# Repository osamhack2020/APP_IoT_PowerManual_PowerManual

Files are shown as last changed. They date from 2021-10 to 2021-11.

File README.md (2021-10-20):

# Project Name: PowerManual
  

## 프로잭트 소개
 - 군대에 들어오고 나서 흔히들 시작하는것 중 하나는 바로 헬스입니다. 20대의 젊은 나이에 멋진 몸을 만들고자 많은 장병들이 부대내 체단실을 이용하면서 하루하루 노력하고 있지만 전문가의 도움 없이 하기에는 어려움도 있고 부상의 위험도 있는 실상입니다. 처음 해보는 장병들은 어떻게 자세를 잡아야할지도 모르겠고 사회에서 헬스를 하다가 온 장병들도 혼자 하다보니 잘못된 자세로 인한 허리부상, 관절부상등을 입는 사례를 종종 목격하고는 합니다. 이렇게 헬스를 할때 가장 중요한 올바른 자세를 정확하게 잡고자 PowerManual은 운동자세 측정 디바이스와 앱을 제공합니다.

## 기능 설명
### 운동자세 측정 디바이스
 - 주기능:  
        디바이스가 착용된 부위의 움직임을 추적하여 운동을 올바른 자세로 하고 있는지 실시간으로 판단하여 판단 결과를 앱으로 전송해줍니다.

 - 구성:  
         
       <팔 또는 다리에 착용할 수 있는 스트랩 형태 *[Tinkercad로 렌더링 예정]*>  
   - 스트랩은 운동할 때 원래 부상방지, 힘 보조등의 이유로 많이 사용되는 만큼 운동할 때 사용자에게 크게 방해가 되지 않는 디자인으로 선정하였습니다.

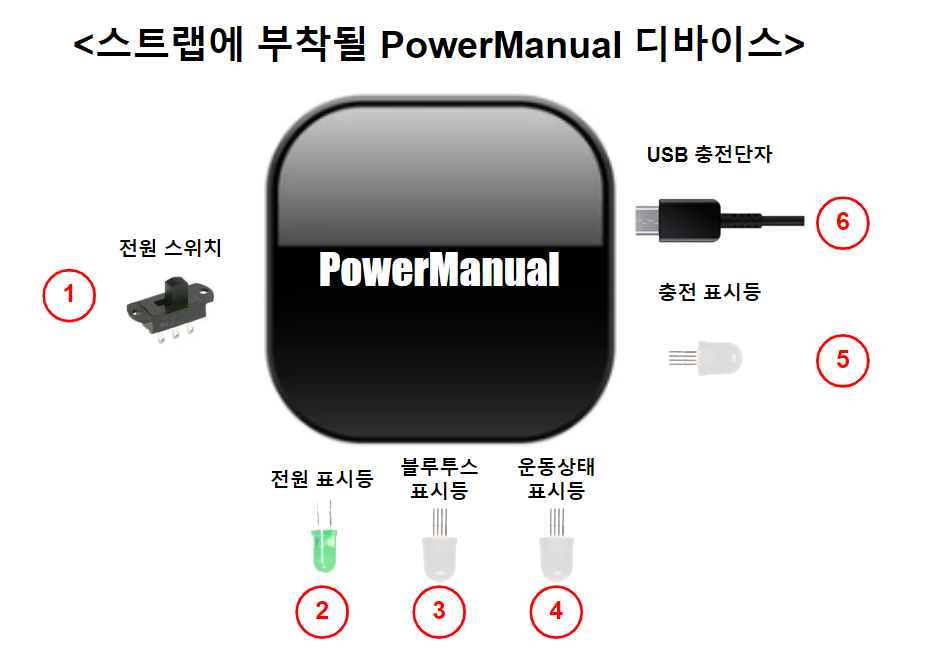
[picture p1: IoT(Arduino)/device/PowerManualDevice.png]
   

   1. 슬라이드 스위치: 디바이스의 전원을 on/off 합니다.   
   2. 내부 MCU LED: 디바이스의 전원이 on이면 초록불이, off면 꺼집니다.  
   3. 내부 블루투스 모듈 LED: 블루투스 기기와 연결되어 있지 않으면 빨간불, 연결 중이면 노란불, 연결상태면 초록불이 켜집니다.   
   4. RGB LED: 앱에서 운동시작 버튼을 누르면 준비자세를 취할 때까지 노란불이 켜지며 준비자세를 유지하면 초록불로 바뀌면서 2초후 운동시작을 나타냅니다. 운동중 자세가 잘못되면 빨간불로 알려줍니다.  
   5. 내부 충전 모듈 LED: 충전중일때는 빨간불이 켜지며 충전이 완료되면 파란불이 켜집니다.  
   6. 내부 충전 모듈 USB 단자: USB충전을 위한 단자가 달려있습니다.  

 - 디바이스 내부:  
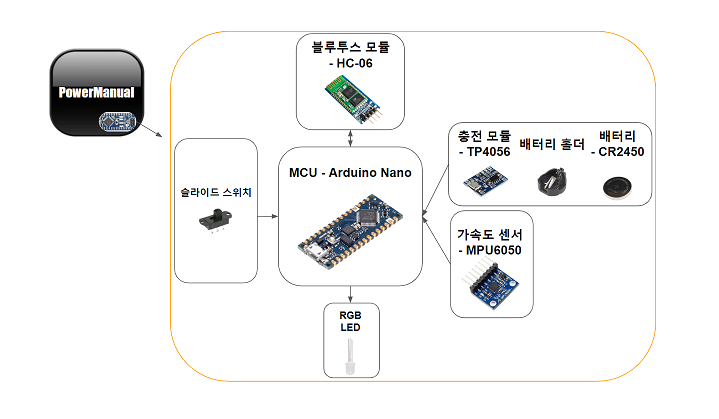
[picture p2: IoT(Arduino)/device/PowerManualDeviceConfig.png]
    

 - 내부 회로도:  
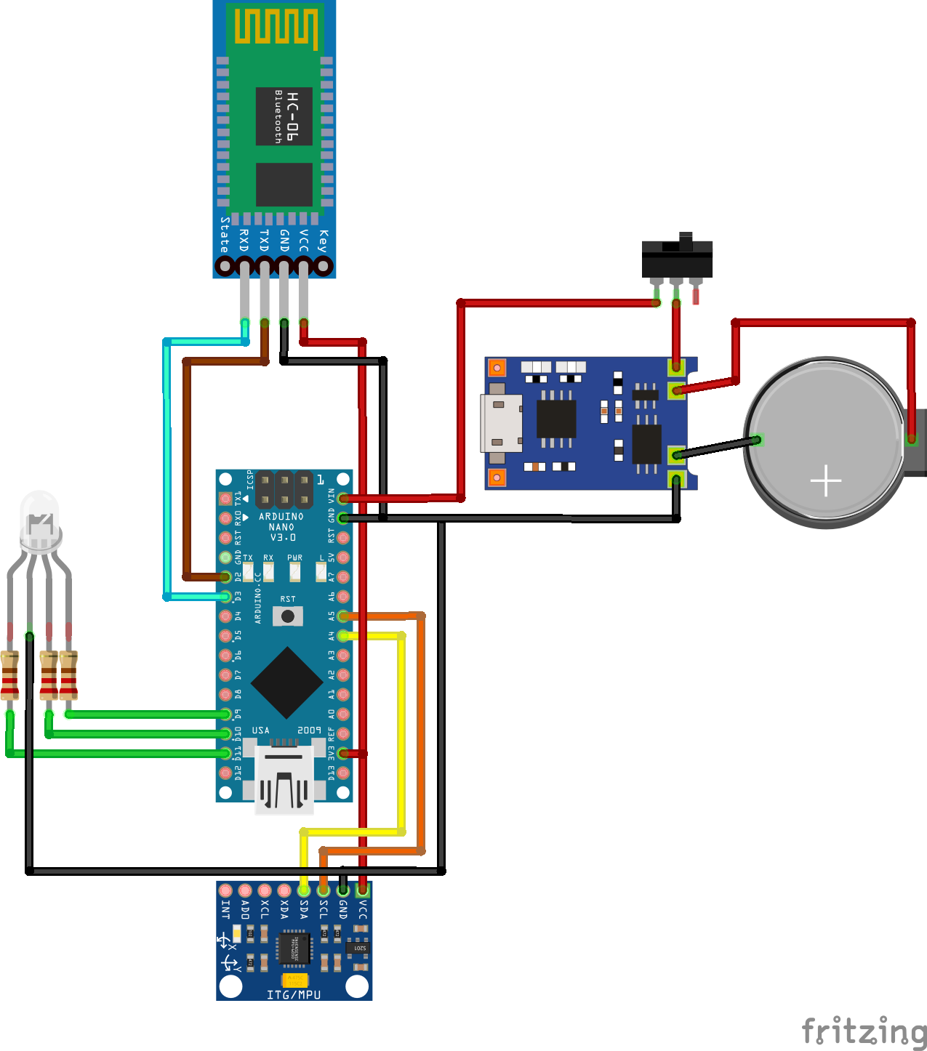
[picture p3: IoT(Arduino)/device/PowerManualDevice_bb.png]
     

## 테스트 모듈 착용 이미지
- 스쿼트 시연시 아래와 같이 허벅지에 착용함
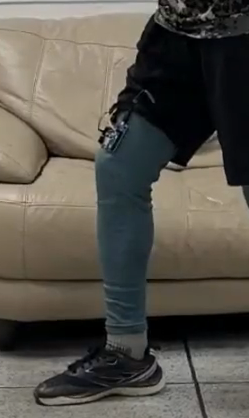
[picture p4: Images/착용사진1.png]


## 시연 영상
* [전원스위치와 LED 시뮬레이션](https://youtu.be/p0WgclJNXeo)
* [스쿼트측정과 운동상태 LED 시뮬레이션](https://youtu.be/8TwuZ1K5hpM)
* [스쿼트측정 시연영상](https://youtu.be/hADi2CqFvGY)
* [종합 시연영상](https://youtu.be/UrrtCfTJw_U)   

## APP

### 화면  
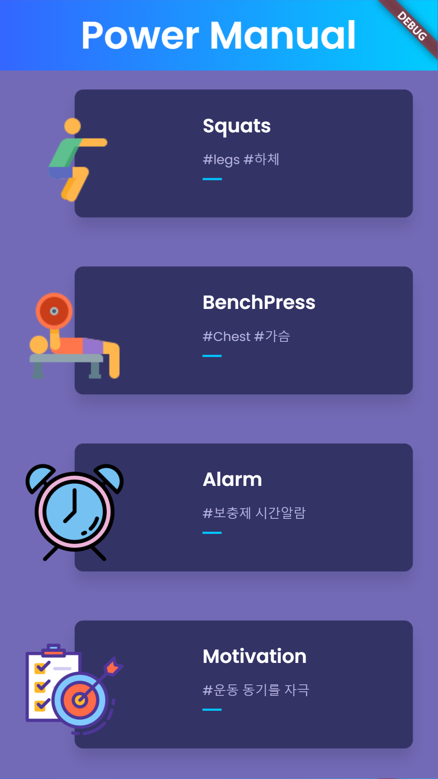
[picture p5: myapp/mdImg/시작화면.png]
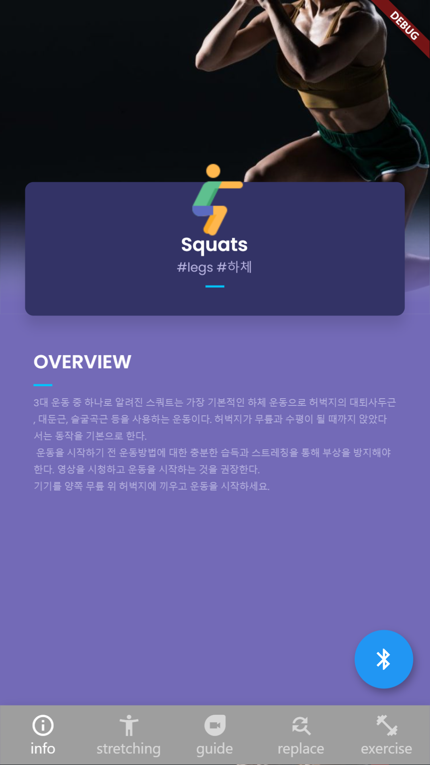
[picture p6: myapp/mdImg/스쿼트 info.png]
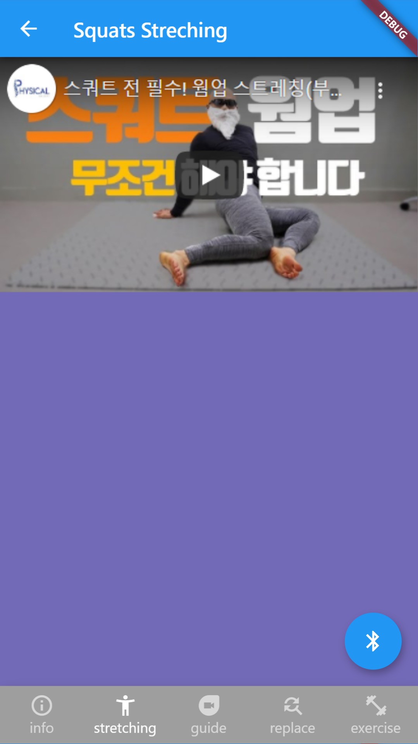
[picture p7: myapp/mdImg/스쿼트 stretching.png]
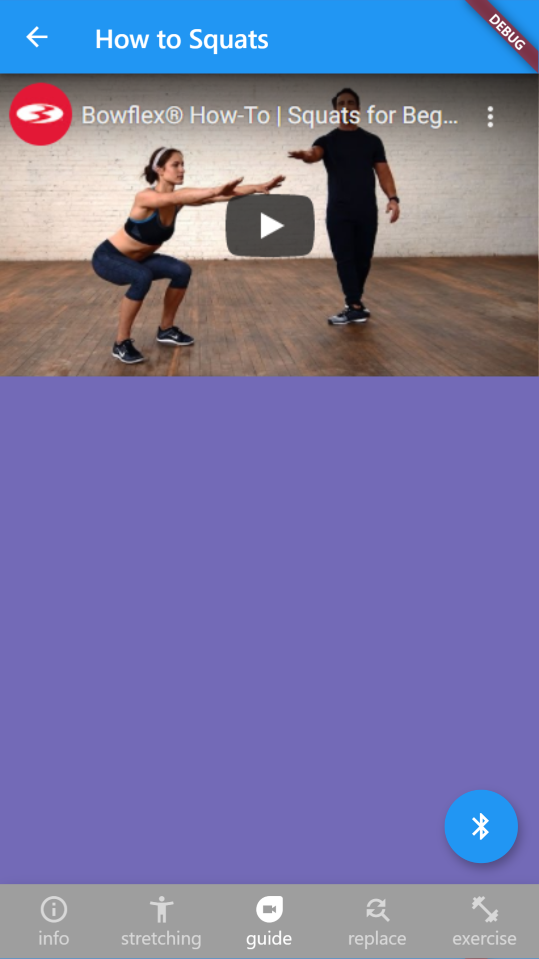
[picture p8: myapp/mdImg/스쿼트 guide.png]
   |  </br> 시작화면|  </br> 스쿼트 info |  </br> 스쿼트 스트레칭 |   </br> 스쿼트 가이드 |
| :------------: | :------------: | :------------: | :------------: |
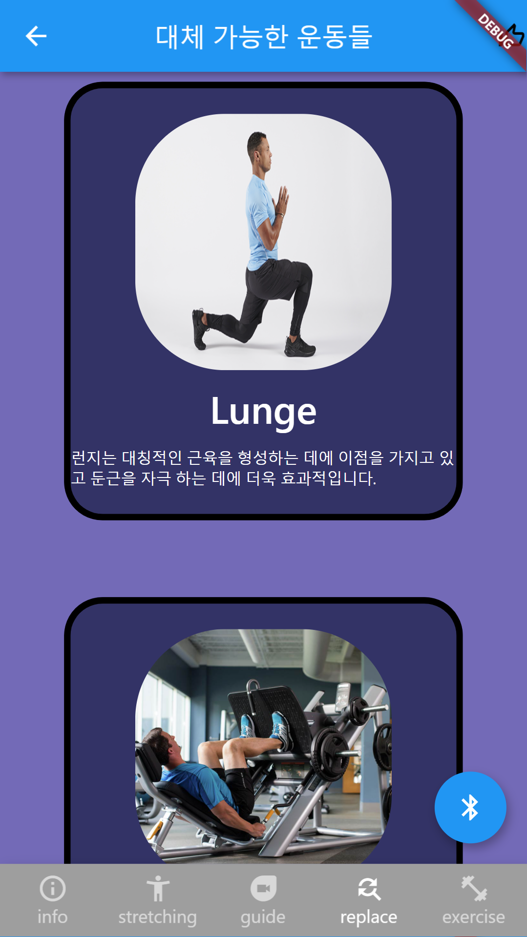
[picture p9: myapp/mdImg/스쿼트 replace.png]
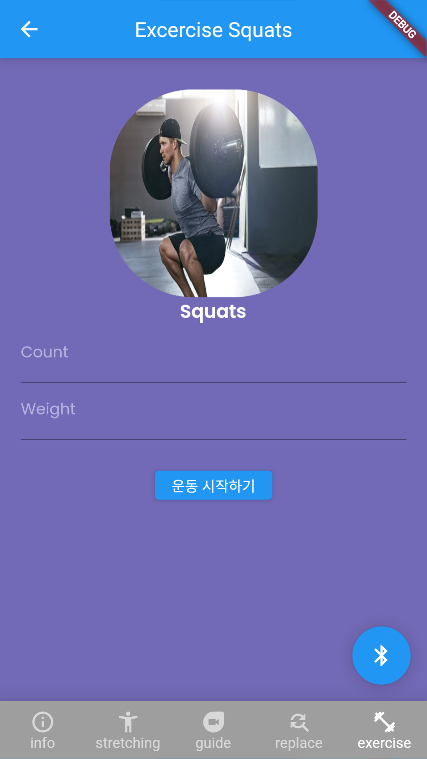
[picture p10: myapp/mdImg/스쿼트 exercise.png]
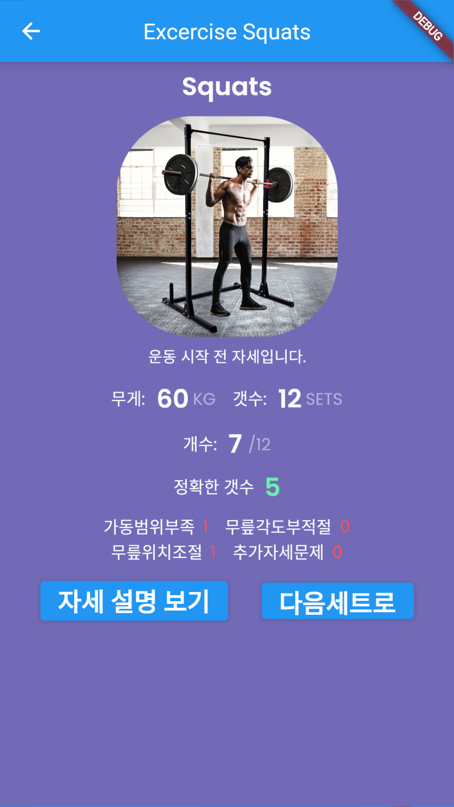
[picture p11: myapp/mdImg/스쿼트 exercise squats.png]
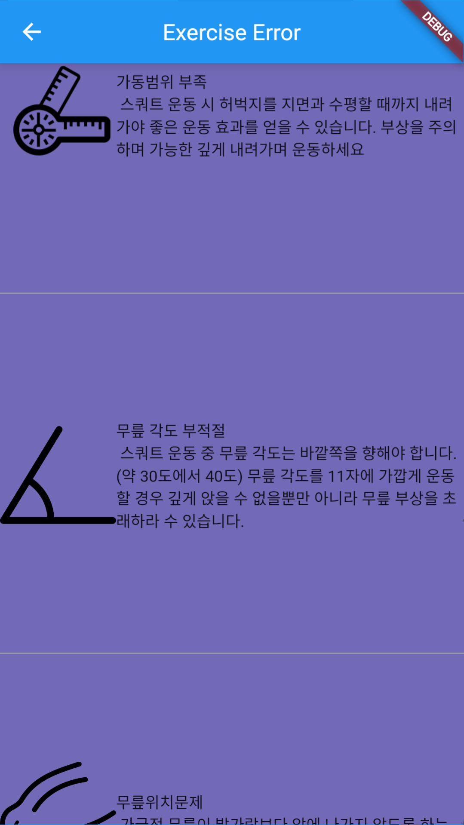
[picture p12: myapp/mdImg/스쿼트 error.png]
|  </br> 스쿼트 대체운동  |  </br> 스쿼트 운동 시작  |   </br> 스쿼트 운동화면 |   </br> 잘못된 자세 교정 화면 |
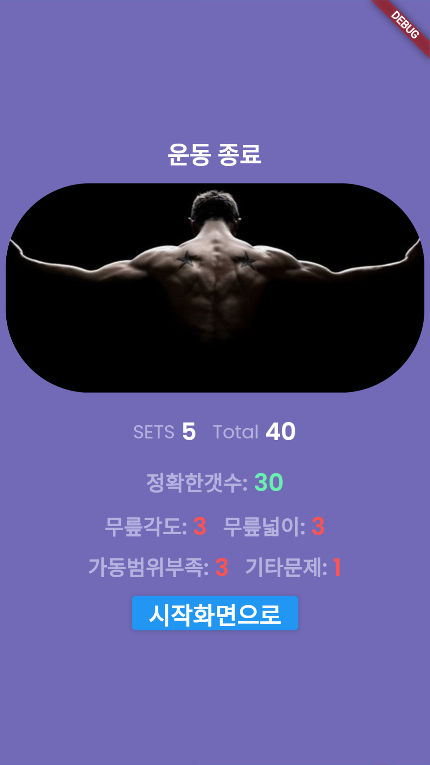
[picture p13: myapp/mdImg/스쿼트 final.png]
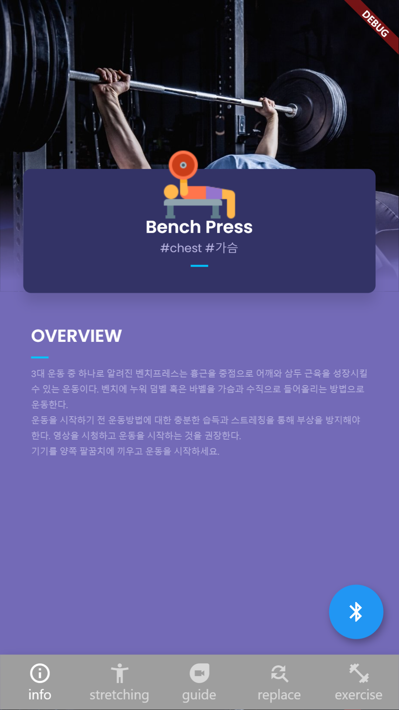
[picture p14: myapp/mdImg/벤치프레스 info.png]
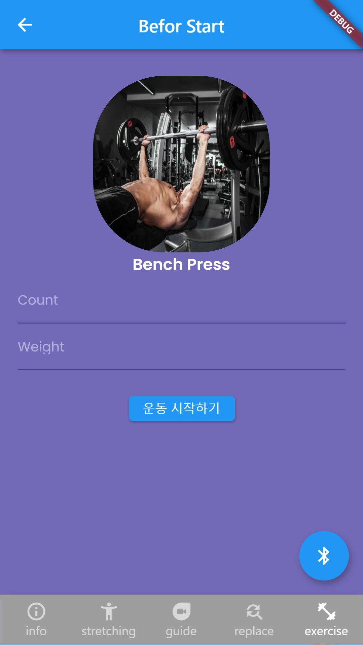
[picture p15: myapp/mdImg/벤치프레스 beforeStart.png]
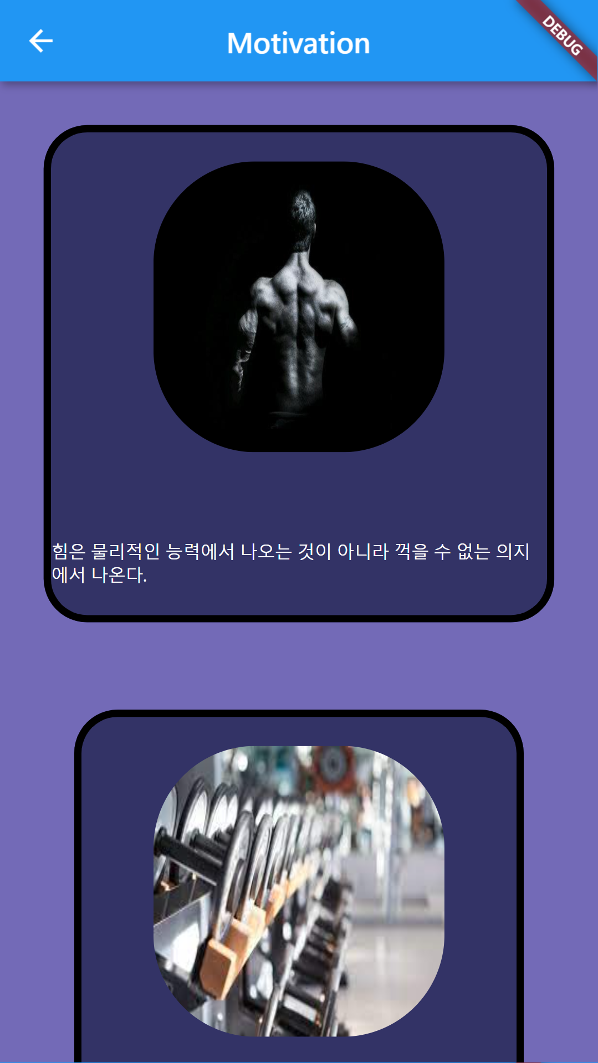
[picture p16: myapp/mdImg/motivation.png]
|  </br> 운동 종료 후 화면  |  </br> 벤치프레스 info |  </br> 벤치프레스 운동시작 |   </br> 운동자극 글귀 |

<!--## 컴퓨터 구성 / 필수 조건 안내 (Prerequisites)
* ECMAScript 6 지원 브라우저 사용
* 권장: Google Chrome 버젼 77 이상
-->
## 기술 스택 (Technique Used) 
### APP
 - Flutter 프레임워크
 - 사용라이브러리: cupertino_icons, youtube_player_iframe, flutter_blue

### Arduino
 -  MsTimer2

## 설치 안내 (Installation Process)
```bash
$ flutter build apk
$ flutter run -d web-server --web-hostname=0.0.0.0
```
<!--
## 프로젝트 사용법 (Getting Started)
**마크다운 문법을 이용하여 자유롭게 기재**

잘 모를 경우
구글 검색 - 마크다운 문법
[https://post.naver.com/viewer/postView.nhn?volumeNo=24627214&memberNo=42458017](https://post.naver.com/viewer/postView.nhn?volumeNo=24627214&memberNo=42458017)

 편한 마크다운 에디터를 찾아서 사용
 샘플 에디터 [https://stackedit.io/app#](https://stackedit.io/app#)
-->
 
## 팀 정보 (Team Information)
- YeChan Lee (tuuktuc86@hanmail.net), Github Id: tuuktuc86
- Taehoon Yang (taehoonyang98@naver.com), Github Id: hooniii98
- SangGyu Oh (sg000515@gmail.com), Github Id: soekam

## 저작권 및 사용권 정보 (Copyleft / End User License)
 * [MIT](https://github.com/osam2020-WEB/Sample-ProjectName-TeamName/blob/master/license.md)

This project is licensed under the terms of the MIT license.

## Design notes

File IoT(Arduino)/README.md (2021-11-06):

 작동순서:  
1. 전원 버튼을 이용하여 디바이스의 전원을 on/off  
2. 전원 LED가 on이 되었음을 알려줌  
3. 블루투스 연결이 자동으로 시작
4. 연결되기 전에는 블루투스모듈의 LED가 깜빡이다가 페어링이 되면 켜진 상태 유지
5. 이후 앱에서 디바이스를 조종하게 됨
6. 운동중이 아닐때는 아두이노의 led가 파란색으로 깜빡거림
7. 앱에서 운동과 횟수를 고르고 운동 시작을 누르면 디바이스가 해당 운동 준비를 시작
8. 운동 상태 LED가 노란불로 시작하여 시작자세를 잡으면 초록불로 변하고 2초후 운동이 시작됨
9. 설정해놓은 횟수가 끝나면 각 횟수마다 잘못되었던 자세 log를 보여주고 그에 따라 점수를 매김

운동 자세 측정 알고리즘:  
1. 스쿼트:  
기본 자세:  
적절하게 다리를 벌리고 서있는 자세에서 시작  
운동 자세:  
다리 각도 유지, 양 무릎은 발 앞까지만, 허벅지는 바닥과 평행한 높이까지 내리고 올라오기, 적당한 속도  

측정 자세:   
1. 허벅지가 바닥과 평행을 이루고 올라오는지  
2. 속도는 적당한지  

동작 구분:  
1. 내려가는 동작  
2. 올라오는 동작  

판단 종류:  
1. 충분히 내려가지 않음  
2. 너무 내려감    
3. 너무 빨리 내려감  
4. 너무 빨리 올라옴  
5. 올바른 자세  

판단 원리:  
실험으로 얻은 데이터를 통해 각 구분 동작마다 기준이 되는 값들을 선정하여 그 값들의 오차범위에 포함되는 측정값들을 올바른 자세로 판단

시연 구성:
1. 전원스위치, 전원 LED, 운동상태 LED: https://www.tinkercad.com/things/6TsqGjZfOjW
2. 가속도센서와 운동상태 LED: 
3. 스쿼트시연

[bluetooth 통신이 serial 통신으로 대체된 데모](https://wokwi.com/arduino/projects/312956629009039936)
\
[통신 명령어](https://github.com/osamhack2021/APP_IoT_PowerManual_PowerManual/tree/main/IoT(Arduino)/bluetooth)

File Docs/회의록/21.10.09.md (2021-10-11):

교차 멘토링  
IoT 김두훈 멘토  

reset하면 보드의 firmware가 초기화되는데 mpu는 계속 값을 보내있음 와치독이란?
angleAcx, angleACy 등등 0으로 초기화하기

칼만필터

앱으로는 serial로 hc-06 slave모드로 serial

아두이노 비동기식은 힘듦 근데 아두이노에서 운동측정값은 interrupt로 계속 앱으로 보냄 한 10ms or 100ms으로
Serial 대기 시켜놓고 받는 준비도 되어있고 보낼 준비도 되어있고

iot 매뉴얼 패키징, 소프트웨어 구성까지

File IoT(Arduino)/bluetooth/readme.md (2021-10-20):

통신할때

아두이노->app

S(운동번호) 운동측정이 시작됨 (시작자세 요청) (스쿼트에 경우 S1)

SW 시작자세가 될 때 까지 대기중

SS 시작자세 확인됨 운동 측정 시작

ED1 너무 높습니다(충분히 내려가지 않음)

EDF 내려갈때너무 빠릅니다.

EDS 내려갈때 너무 느립니다

EDC 정상 속도

ED2 너무 낮습니다(너무 많이 내려감)

EUF 올라갈때 너무 빠릅니다

EUS 올라갈때 너무 빠릅니다

EUC 올라갈때 너무 빠릅니다

WC 잘못된 명령어(제대로만 되었다면 뜨면 안됨)

F 1개끝

FF 정해진 갯수 끝

app->arduino

SSSS 중단

E(운동번호)(운동횟수)   0 ~ 9 운동번호(스쿼트는 1번) 1 ~ 99 운동횟수

ex)

E130 첫번째 운동(스쿼트) 30개

E399 세번재 운동 99개

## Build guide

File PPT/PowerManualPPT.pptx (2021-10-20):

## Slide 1

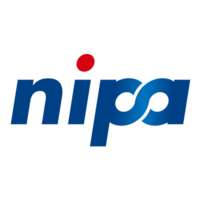
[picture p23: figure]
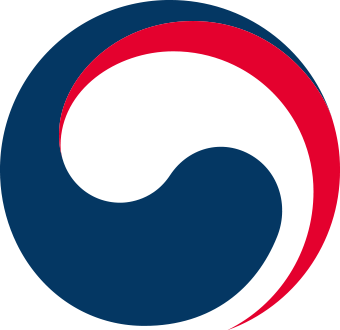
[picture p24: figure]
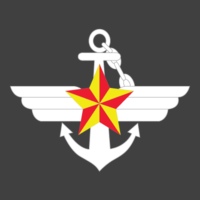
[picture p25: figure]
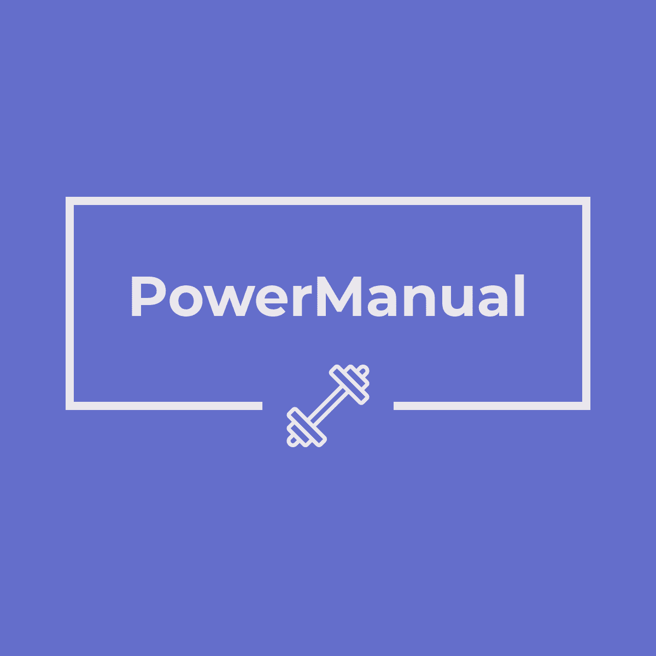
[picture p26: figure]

PowerManual
웨어러블 헬스 트레이닝 디바이스/앱

팀 체력단련하실 제작

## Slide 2

팀 소개
프로젝트 소개
개발과정
기대효과
사용 기술 및 오픈소스

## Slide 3

팀 소개

CONTENTS

01

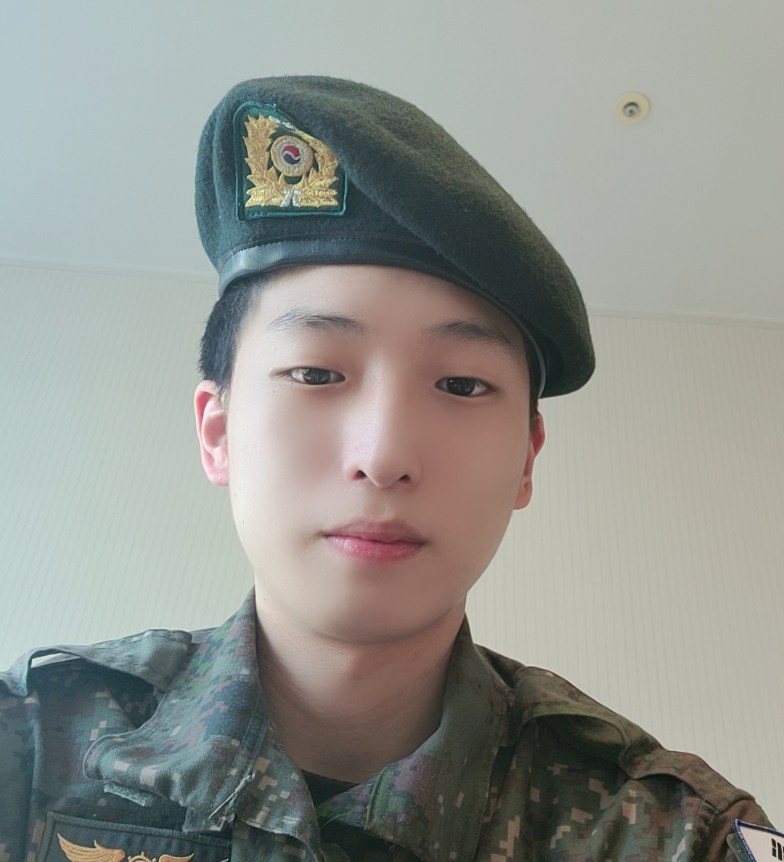
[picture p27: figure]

양태훈 팀원
IoT 센서 개발
노스이스턴대학교 전기전자컴퓨터공학과
육군 상병 무선장비정비병

이예찬 팀장
기획, 앱 개발
Enjoy your stylish business and campus life with BIZCAM

오상규 팀원
IoT 통신 개발
Enjoy your stylish business and campus life with BIZCAM

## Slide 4

프로젝트 소개

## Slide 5

프로젝트 소개

PowerManual 이란?

웨어러블 디바이스를 통해 운동 모션을 감지하고 판단한 후 핸드폰 앱으로 보여주는 앱/IoT 통합 헬스 트레이닝 시스템

왜 필요한가?

많은 장병들이 입대후 헬스를 시작하지만 전문적인 도움없이 하다 보니 초보자, 경험자 상관없이 운동에 어려움을 겪거나 비전투손실을 겪는 상황까지 발생하고 있다.

CONTENTS

02

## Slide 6

개발과정

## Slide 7

IoT 개발과정

운동 모션을 어떻게 측정?

- 드론에도 탑재되는 가속도 센서를 이용
- 내부에 두개의 센서(가속도와 자이로 센서)가 탑재해 있는데 두개를 상호보완필터를 이용하여 결합하면 실시간 움직임을 정밀하게 측정이 가능함

CONTENTS

02

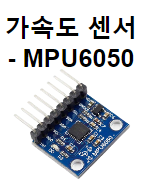
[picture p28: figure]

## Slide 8

IoT 개발과정

디바이스 구성

- 운동을 하는데 방해되지 않게 작은 아두이노 나노 MCU와 가속도 센서로 구성하고 추가적인 스위치, LED, 배터리등은 최소한으로 구성
- 우측 그림의 컨트롤러같이 스트랩을 이용하여 착용
- 스트랩은 운동할 때 원래 부상방지, 힘 보조등의 이유로 많이 사용되는 만큼 운동시 크게 방해되지 않음

CONTENTS

02

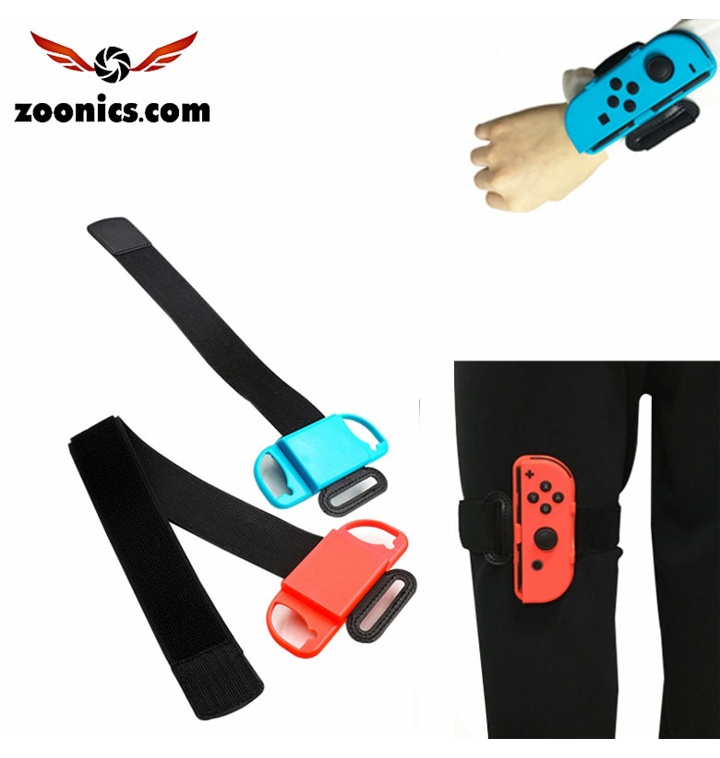
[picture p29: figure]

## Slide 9

IoT 개발과정

CONTENTS

02

디바이스 구성


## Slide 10

IoT 개발과정

CONTENTS

02

디바이스 내부 구성


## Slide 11

IoT 개발과정

CONTENTS

02

디바이스 내부 회로도


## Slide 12

IoT 개발과정

디바이스 내부 회로도

- 시연영상에서 각각의 부품들이 제대로 동작하는지 시뮬레이션과 실제 실험이 진행되어 있음
- 시연영상 링크: https://youtu.be/gCXsnY9W7Xc

CONTENTS

02

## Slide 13

기대효과

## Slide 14

기대효과

헬스의 일반화 & 대중화

- 코로나시대에 접어들면서 4차 산업혁명의 가속화와 더불어 집콕문화가 생기며 집안에서의 개인건강에 대한 관심도 증가하고 있다.
- IoT와 앱을 결합한 웨어러블 디바이스를 통해 꼭 군부대내에서뿐만 아니라 모든 사람이 헬스장에 가지 않고도 PT를 받는 것과 같이 헬스를 쉽고 안전하게 접근하여 진입장벽을 낮추고 대중화를 통해 건강한 헬스문화가 자리잡는 것에 도움을 줄 것이다.

CONTENTS

02

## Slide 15

사용 기술 및 오픈소스

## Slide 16

사용 기술 및 오픈소스

사용 기술

- IoT: Arduino, Fritzing(회로 디자인), TinkerCAD(시뮬레이션), Wokwi(시뮬레이션)

CONTENTS

02

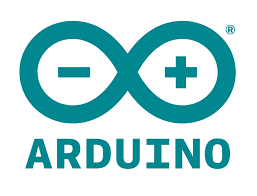
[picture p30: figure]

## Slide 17

PPT PRESENTATION Enjoy your stylish business and campus life with BIZCAM

CONTENTS

01

75%

CONTENTS A
컨텐츠에 대한 내용을 적어요
Enjoy your stylish business and campus life with BIZCAM

75%

CONTENTS A
컨텐츠에 대한 내용을 적어요
Enjoy your stylish business and campus life with BIZCAM

START

FINISH

CONTENTS A
컨텐츠에 대한 내용을 적어요
Enjoy your stylish business and campus life with BIZCAM

75%

CONTENTS A
컨텐츠에 대한 내용을 적어요
Enjoy your stylish business and campus life with BIZCAM

75%

CONTENTS A
컨텐츠에 대한 내용을 적어요
Enjoy your stylish business and campus life with BIZCAM

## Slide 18

PPT PRESENTATION Enjoy your stylish business and campus life with BIZCAM

CONTENTS

01

CONTENTS A
컨텐츠에 대한 내용을 적어요
Enjoy your stylish business and campus life with BIZCAM

CONTENTS A
컨텐츠에 대한 내용을 적어요
Enjoy your stylish business and campus life with BIZCAM

CONTENTS A
컨텐츠에 대한 내용을 적어요
Enjoy your stylish business and campus life with BIZCAM

CONTENTS A
컨텐츠에 대한 내용을 적어요
Enjoy your stylish business and campus life with BIZCAM

CONTENTS A
컨텐츠에 대한 내용을 적어요
Enjoy your stylish business and campus life with BIZCAM

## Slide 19

PPT PRESENTATION Enjoy your stylish business and campus life with BIZCAM

CONTENTS

01

70%
90%

CONTENTS A
컨텐츠에 대한 내용을 적어요
Enjoy your stylish business and campus life with BIZCAM

50%
(20대)

80%
(30대)

70%
90%

CONTENTS A
컨텐츠에 대한 내용을 적어요
Enjoy your stylish business and campus life with BIZCAM

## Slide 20

오늘 사용한 색상은?

R 71
G 74
B 155

R 244
G 107
B 100

2013 버전 이상 사용자께서는 스포이트 기능을 이용하시면 편하구요.
2010 이하 버전 사용자 께서는 다른 채우기 색 > 사용자 지정 탭 > RGB 색상 값 입력

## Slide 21

최근 저의 자료를 카페 등에 무단으로 재배포 하는 일이 자주 발생하고 있습니다.
이에 대해 굉장히 심각한 문제로 받아 들이고 있으며,
해당 문제가 반복될 경우, 재배포한 자에 대해서는 그에 대한 책임을 반드시 물을 것입니다.
저작권을 존중하지 않는 극히 소수의 사용자로 인해 다수가 피해를 보지 않도록 주의해 주시면 감사하겠으며
제 자료가 업로드 된 곳이 있다면 저에게 알려주시면 감사하겠습니다.
제 자료를 소개하고자 할 경우에는
pptbizcam 사이트로의 링크 처리로만 가능하며
파일 자체를 업로드 하는 것은 불가한 점 유의해 주시면 감사하겠습니다.
홍보, 경제적 이익을 취하는 행위 또한 불가합니다.
※기타 활용 가능 범위는 공유 사이트 -> 수다방 게시판 공지사항 참고

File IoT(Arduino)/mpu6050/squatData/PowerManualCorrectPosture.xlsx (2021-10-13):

X | 시작 자세 X | 3.59 | Y | 시작 자세 Y | -85.62 | Z | 시작 자세 Z | 0.01
X | 3.318780488 | 3.37 | Y | -85.73073171 | -85.8 | Z | 0.201463415 | 0.02
X |  | 3.65 | Y |  | -85.44 | Z |  | -0.13
X |  | 3.76 | Y |  | -85.37 | Z |  | -0.17
X |  | 3.61 | Y |  | -85.4 | Z |  | -0.17
X |  | 3.89 | Y |  | -85.15 | Z |  | -0.1
X |  | 3.91 | Y |  | -85.2 | Z |  | 0
X |  | 4.06 | Y |  | -85.15 | Z |  | 0
X |  | 3.81 | Y |  | -85.43 | Z |  | 0.14
X |  | 4.03 | Y |  | -85.29 | Z |  | -0.02
X |  | 4.17 | Y |  | -85.26 | Z |  | 0.1
X |  | 3.99 | Y |  | -85.49 | Z |  | 0.13
X |  | 3.89 | Y |  | -85.61 | Z |  | 0.21
X |  | 3.94 | Y |  | -85.42 | Z |  | 0.31
X |  | 3.62 | Y |  | -85.67 | Z |  | 0.38
X |  | 3.51 | Y |  | -85.78 | Z |  | 0.34
X |  | 3.67 | Y |  | -85.61 | Z |  | 0.33
X |  | 3.48 | Y |  | -85.87 | Z |  | 0.39
X |  | 3.45 | Y |  | -85.82 | Z |  | 0.35
X |  | 3.56 | Y |  | -85.63 | Z |  | 0.33
X |  | 3.24 | Y |  | -85.97 | Z |  | 0.15
X |  | 3.42 | Y |  | -85.85 | Z |  | 0.09
X |  | 3.92 | Y |  | -85.29 | Z |  | 0
X |  | 3.41 | Y |  | -85.62 | Z |  | 0.1
X |  | 2.92 | Y |  | -85.99 | Z |  | 0.27
X |  | 2.99 | Y |  | -85.93 | Z |  | 0.31
X |  | 2.99 | Y |  | -85.91 | Z |  | 0.3
X |  | 2.91 | Y |  | -85.98 | Z |  | 0.28
X |  | 2.86 | Y |  | -86.02 | Z |  | 0.31
X |  | 2.84 | Y |  | -86 | Z |  | 0.33
X |  | 2.79 | Y |  | -86.08 | Z |  | 0.32
X |  | 2.78 | Y |  | -86.08 | Z |  | 0.4
X |  | 2.76 | Y |  | -86.06 | Z |  | 0.37
X |  | 2.73 | Y |  | -86.07 | Z |  | 0.4
X |  | 2.73 | Y |  | -86.05 | Z |  | 0.37
X |  | 2.73 | Y |  | -86.03 | Z |  | 0.36
X |  | 2.71 | Y |  | -86.05 | Z |  | 0.37
X |  | 2.68 | Y |  | -86.02 | Z |  | 0.32
X |  | 2.67 | Y |  | -86.02 | Z |  | 0.36
X |  | 2.52 | Y |  | -86.12 | Z |  | 0.35
X |  | 2.51 | Y |  | -85.81 | Z |  | 0.05
X |  | 2.05 | Y |  | -85.36 | Z |  | 0.25
X |  | 2.62 | Y |  | -82.85 | Z |  | 0.79
X |  | 2.98 | Y |  | -79.66 | Z |  | 0.77
X |  | 2.96 | Y |  | -76.27 | Z |  | 1.05
X |  | 3.5 | Y |  | -72.74 | Z |  | 1.08
X |  | 3.84 | Y |  | -69.44 | Z |  | 1.46
X |  | 3.29 | Y |  | -66.16 | Z |  | 1.18
X |  | 2.56 | Y |  | -61.31 | Z |  | 0.45
X |  | 2.23 | Y |  | -56.84 | Z |  | 0.14
X |  | 2.99 | Y |  | -52.6 | Z |  | 0.57
X |  | 3.78 | Y |  | -49.18 | Z |  | 1.3
X |  | 4 | Y |  | -46.2 | Z |  | 1.18
X |  | 4.05 | Y |  | -42.7 | Z |  | 0.78
X |  | 5.27 | Y |  | -38.77 | Z |  | 0.25
X |  | 5 | Y |  | -33.85 | Z |  | 0.23
X |  | 5.43 | Y |  | -30.83 | Z |  | 0.19
X |  | 5.33 | Y |  | -27.64 | Z |  | 0.24
X |  | 5.36 | Y |  | -24.75 | Z |  | 0.25
X |  | 4.32 | Y |  | -23.56 | Z |  | 0.2
X |  | 3.96 | Y |  | -21.9 | Z |  | 0.17
X |  | 2.74 | Y |  | -19.75 | Z |  | -0.75
X |  | 2.17 | Y |  | -16.26 | Z |  | -0.87
X |  | 2.39 | Y |  | -13.21 | Z |  | -1.33
X |  | 1.69 | Y |  | -9.61 | Z |  | -1.44
X |  | 1.48 | Y |  | -6.27 | Z |  | -1.25
X |  | 1.08 | Y |  | -3.11 | Z |  | -1.66
X |  | 1.07 | Y |  | -1.22 | Z |  | -1.89
X |  | 1.15 | Y |  | 1.19 | Z |  | -2.26
X |  | 1.95 | Y |  | 2.86 | Z |  | -2.51
X |  | 1.74 | Y |  | 4.88 | Z |  | -2.01
X |  | 1.34 | Y |  | 5.92 | Z |  | -1.56
X |  | 0.72 | Y |  | 6.32 | Z |  | -1.83
X |  | 0.85 | Y |  | 7.44 | Z |  | -1.97
X |  | 0.62 | Y |  | 8.31 | Z |  | -2.04
X |  | 0.75 | Y |  | 8.74 | Z |  | -2.09
X |  | 1.58 | Y |  | 8.68 | Z |  | -1.99
X |  | 0.87 | Y |  | 8.9 | Z |  | -2.11
X |  | 0.09 | Y |  | 10.62 | Z |  | -2.44
X |  | -0.54 | Y |  | 10.53 | Z |  | -2.23
X |  | -0.66 | Y |  | 9.41 | Z |  | -2.72
X |  | -1.14 | Y |  | 6.6 | Z |  | -2.38
X |  | 0.48 | Y |  | 3.86 | Z |  | -2.04
X |  | 0.2 | Y |  | 0.31 | Z |  | -1.71
X |  | 0.86 | Y |  | -3.34 | Z |  | -1.45
X |  | 1.17 | Y |  | -8.26 | Z |  | -1.61
X |  | 0.24 | Y |  | -12.93 | Z |  | -1.84
X |  | 0.23 | Y |  | -17.93 | Z |  | -1.27
X |  | 0.7 | Y |  | -22.86 | Z |  | -0.87
X |  | 1.51 | Y |  | -27.35 | Z |  | -0.66
X |  | 1.98 | Y |  | -31.55 | Z |  | 0.13
X |  | 1.23 | Y |  | -35.46 | Z |  | 0.68
X |  | 0.83 | Y |  | -39.77 | Z |  | 1.01
X |  | 0.5 | Y |  | -44.5 | Z |  | 0.8
X |  | 0.59 | Y |  | -48.88 | Z |  | 0.75
X |  | 0.91 | Y |  | -52.91 | Z |  | 0.89
X |  | 0.47 | Y |  | -56.94 | Z |  | 1
X |  | 0.22 | Y |  | -60.34 | Z |  | 0.19
X |  | 1.17 | Y |  | -63.32 | Z |  | -0.75
X |  | 1.77 | Y |  | -66.14 | Z |  | -0.74
X |  | 2.11 | Y |  | -70.1 | Z |  | -0.83
X |  | 2.16 | Y |  | -73.95 | Z |  | -1.12
X |  | 2.81 | Y |  | -76.9 | Z |  | -1.25
X |  | 2.12 | Y |  | -80.54 | Z |  | -1.79
X |  | 2.53 | Y |  | -82.85 | Z |  | -2.38
X |  | 3.23 | Y |  | -83.44 | Z |  | -2.67
X |  | 2.86 | Y |  | -84.14 | Z |  | -2.44
X |  | 2.65 | Y |  | -84.54 | Z |  | -2.4
X |  | 2.71 | Y |  | -84.66 | Z |  | -2.4
X |  | 2.81 | Y |  | -84.7 | Z |  | -2.29
X |  | 2.76 | Y |  | -84.83 | Z |  | -2.19
X |  | 2.97 | Y |  | -84.64 | Z |  | -2.19
X |  | 2.79 | Y |  | -84.61 | Z |  | -2.25
X |  | 2.85 | Y |  | -84.63 | Z |  | -2.3
X |  | 2.74 | Y |  | -84.67 | Z |  | -2.35
X |  | 2.85 | Y |  | -84.6 | Z |  | -2.36
X |  | 2.76 | Y |  | -84.64 | Z |  | -2.37
X |  | 2.71 | Y |  | -84.58 | Z |  | -2.47
X |  | 2.78 | Y |  | -84.55 | Z |  | -2.48
X |  | 2.83 | Y |  | -84.51 | Z |  | -2.54
X |  | 2.81 | Y |  | -84.46 | Z |  | -2.57
X |  | 2.8 | Y |  | -84.42 | Z |  | -2.59
X |  | 2.76 | Y |  | -84.52 | Z |  | -2.63
X |  | 2.77 | Y |  | -84.57 | Z |  | -2.67
X |  | 2.65 | Y |  | -84.47 | Z |  | -2.64
X |  | 2.75 | Y |  | -84.32 | Z |  | -2.68
X |  | 2.66 | Y |  | -84.45 | Z |  | -2.66
X |  | 2.43 | Y |  | -84.55 | Z |  | -2.54
X |  | 2.5 | Y |  | -84.72 | Z |  | -2.68
X |  | 2.56 | Y |  | -84.47 | Z |  | -2.63
X |  | 2.34 | Y |  | -84.76 | Z |  | -2.69
X |  | 2.84 | Y |  | -84.34 | Z |  | -2.7
X |  | 2.95 | Y |  | -84.24 | Z |  | -2.63
X |  | 2.96 | Y |  | -84.34 | Z |  | -2.64

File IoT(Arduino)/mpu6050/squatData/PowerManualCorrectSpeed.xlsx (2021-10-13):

X | 시작 자세 X | -4.27 | Y | 시작 자세 Y | -87.35 | Z | 시작 자세 Z | -2.99
X | -5.0232 | -4.32 | Y | -87.4552 | -87.35 | Z | -3.2448 | -3.04
X |  | -4.46 | Y |  | -87.46 | Z |  | -3.18
X |  | -4.37 | Y |  | -87.22 | Z |  | -3.29
X |  | -4.85 | Y |  | -87.61 | Z |  | -3.28
X |  | -4.71 | Y |  | -87.43 | Z |  | -3.37
X |  | -4.71 | Y |  | -87.46 | Z |  | -3.43
X |  | -4.79 | Y |  | -87.49 | Z |  | -3.39
X |  | -4.86 | Y |  | -87.56 | Z |  | -3.36
X |  | -4.91 | Y |  | -87.54 | Z |  | -3.38
X |  | -5.08 | Y |  | -87.69 | Z |  | -3.38
X |  | -5.17 | Y |  | -87.68 | Z |  | -3.4
X |  | -5 | Y |  | -87.52 | Z |  | -3.34
X |  | -5.1 | Y |  | -87.58 | Z |  | -3.27
X |  | -5.1 | Y |  | -87.5 | Z |  | -3.29
X |  | -5.26 | Y |  | -87.61 | Z |  | -3.26
X |  | -5.17 | Y |  | -87.49 | Z |  | -3.15
X |  | -5.16 | Y |  | -87.45 | Z |  | -3.16
X |  | -5.32 | Y |  | -87.54 | Z |  | -3.15
X |  | -5.26 | Y |  | -87.47 | Z |  | -3.17
X |  | -5.36 | Y |  | -87.55 | Z |  | -3.13
X |  | -5.41 | Y |  | -87.53 | Z |  | -3.13
X |  | -5.21 | Y |  | -87.24 | Z |  | -3.15
X |  | -5.82 | Y |  | -87.49 | Z |  | -3.15
X |  | -5.91 | Y |  | -86.57 | Z |  | -3.28
X |  | -5.6 | Y |  | -85.24 | Z |  | -2.81
X |  | -6.08 | Y |  | -80.64 | Z |  | -2.64
X |  | -3.91 | Y |  | -71.99 | Z |  | -3.17
X |  | -2.73 | Y |  | -61.01 | Z |  | -3.89
X |  | -3.44 | Y |  | -49.92 | Z |  | -4.89
X |  | -3.02 | Y |  | -39.46 | Z |  | -5.79
X |  | -1.38 | Y |  | -29.77 | Z |  | -7.34
X |  | -1.59 | Y |  | -20.13 | Z |  | -7.17
X |  | -4.31 | Y |  | -11.45 | Z |  | -7.5
X |  | -7.37 | Y |  | -1.43 | Z |  | -7.72
X |  | -7.38 | Y |  | 5.83 | Z |  | -7.74
X |  | -8.08 | Y |  | 12.53 | Z |  | -8.14
X |  | -9.27 | Y |  | 16 | Z |  | -8.02
X |  | -9.38 | Y |  | 15.16 | Z |  | -6.99
X |  | -9.05 | Y |  | 10.7 | Z |  | -6.76
X |  | -8.79 | Y |  | 1.7 | Z |  | -6.47
X |  | -10.18 | Y |  | -9 | Z |  | -6.3
X |  | -9.18 | Y |  | -21.6 | Z |  | -6.43
X |  | -8.88 | Y |  | -35.16 | Z |  | -6.66
X |  | -7.94 | Y |  | -48.73 | Z |  | -6.49
X |  | -6.9 | Y |  | -61.91 | Z |  | -6.7
X |  | -6.65 | Y |  | -73.98 | Z |  | -8.16
X |  | -6.23 | Y |  | -81.12 | Z |  | -8.93
X |  | -5.84 | Y |  | -84.28 | Z |  | -9.12
X |  | -5.14 | Y |  | -85.1 | Z |  | -9.26
X |  | -5.28 | Y |  | -85.97 | Z |  | -9.3
X |  | -5.37 | Y |  | -86.3 | Z |  | -9.23
X |  | -5.53 | Y |  | -86.51 | Z |  | -9.23
X |  | -5.56 | Y |  | -86.57 | Z |  | -9.12
X |  | -5.82 | Y |  | -86.9 | Z |  | -9.02
X |  | -5.89 | Y |  | -86.92 | Z |  | -8.93
X |  | -6.12 | Y |  | -87.11 | Z |  | -8.92
X |  | -6.12 | Y |  | -87.09 | Z |  | -8.94
X |  | -6.24 | Y |  | -87.13 | Z |  | -8.92
X |  | -6.04 | Y |  | -86.96 | Z |  | -8.83
X |  | -5.85 | Y |  | -87.01 | Z |  | -8.89
X |  | -5.64 | Y |  | -86.87 | Z |  | -8.86
X |  | -5.36 | Y |  | -86.72 | Z |  | -8.83
X |  | -5.6 | Y |  | -86.96 | Z |  | -8.82

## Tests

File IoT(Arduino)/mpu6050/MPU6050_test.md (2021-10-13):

WOKWI: MPU6050 시뮬레이터  
Fritzing: 회로 시뮬레이터  
사용된 부품: Arduino Nano, GY-521 모듈(MPU6050 센서)

참고 자료:  
https://rasino.tistory.com/325 => MPU6050 센서 실습(MPU Library 사용 X)  
https://diymaker.tistory.com/79 => Arduino Nano I2C pinmap  
https://www.hackster.io/Hack-star-Arduino/arduino-simulator-adafruit-mpu6050-gyro-accelorometer-9678d6 => Virtual Arduino Simulator with MPU6050  
https://scienceon.kisti.re.kr/srch/selectPORSrchArticle.do?cn=JAKO202031064817950&dbt=NART => 관성 센서기반 스쿼트 각도 측정 융합 시스템 논문  

1차 Test:  
"Raw 데이터 얻기"  
https://wokwi.com/arduino/projects/311299741125182016  
기울기 센서가 움직임에 따라 raw데이터도 변함
시뮬레이션에서 x축 0, y축 0, z축 1g 상태는 기울기 센서가 위를 바라보며 가만히 놓여있는 상태이다.  

2차 Test:  
"Accelerometer로 부터 angle 얻기"
https://wokwi.com/arduino/projects/311317515851530816  
1차와 같은 회로 사용
움직임이 없는 상태에서 보다 정확한 값을 얻을 수 있음  
가속도 센서는 z축 회전각 계산 불가  

3차 Test:  
"Gyro로 부터 angle 얻기"
https://wokwi.com/arduino/projects/311333884930294337  
1차와 같은 회로 사용
축을 중심으로 회전하는 각속도를 측정한 뒤 적분하여 기울어진 각도를 계산  
노이즈나 미세한 기본 오차 값들이 적분으로 인해, 시간이 지날 수록 측정값의 오차가 커지는 Drift현상 발생  
하지만, 가속도 센서와 달리 진동에 영향이 크게 없으며 중fur과 일치하는 Z축의 Yaw 각도도 구할 수 있음  
또한, 평균값을 사용하여 spike와 같은 오차를 줄임

4차 Test:  
"Complementary Filter로 angle 얻기"  
https://wokwi.com/arduino/projects/311334970688799296  
가속도 센서는 고주파 영역의 노이즈를 감쇠시키고 낮은 주파수 영역을 통과시키는 저역필터를 적용  
자이로 센서는 저주파 영역의 노이즈를 감쇠시키는 높은 주파수 영역을 통과시키는 고역필터를 적용    
가중치는 임의로 정해져 있으나 실험을 통해 실제 각도기를 이용한 측정값과 가장 가까울 때의 가중치가 구해져야 함  
가중치를 과도하게 조정하면 출력 딜레이가 발생하므로 주의  
cf)칼만필터(출력 딜레이를 줄여주는 필터)는 드론과 같이 빠른 반응이 중요한 곳에 사용하므로 우리 PowerManual에는 불필요함  

6차 Test:

Testbed  
구성:  
Wemos D1 R2, MPU6050

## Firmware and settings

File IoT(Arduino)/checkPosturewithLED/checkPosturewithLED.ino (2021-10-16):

// 스쿼트자세 측정완료 + 운동상태 LED
// https://wokwi.com/arduino/projects/312524496739238465

#include<Wire.h>  // MPU6050과 I2C 통신을 위한 라이브러리
#include<math.h>

const int MPU_ADDR = 0x68;    // I2C통신을 위한 MPU6050의 주소
int16_t AcX = 0, AcY = 0, AcZ = 0, Tmp = 0, GyX = 0, GyY = 0, GyZ = 0;   // 가속도(Acceleration)와 자이로(Gyro)
double angleAcX = 0, angleAcY = 0, angleAcZ = 0;
double angleGyX = 0, angleGyY = 0, angleGyZ = 0;
double angleFiX = 0, angleFiY = 0, angleFiZ = 0;

const double RADIAN_TO_DEGREE = 57.29583;  
const double DEG_PER_SEC = 131.068;    // 1초에 회전하는 각도
const double ALPHA = 0.92; //1 / (1 + 0.04); 
// GyX, GyY, GyZ 값의 범위 : -32768 ~ +32767 (16비트 정수범위)


unsigned long now = 0;   // 현재 시간 저장용 변수
unsigned long past = 0;  // 이전 시간 저장용 변수
double dt = 0;           // 한 사이클 동안 걸린 시간 변수

double averAcX = 0, averAcY = 0, averAcZ = 0;
double averGyX = 0, averGyY = 0, averGyZ = 0;

int count = 0;  // getAngle() 내부용 카운터 변수

int squat = 1;
int exercise  = 1;  //앱으로 부터 어떤 운동을 수행할지 전달받는 변수; 처음 값은 0 지금은 squat 시연용이어서 1
int reps = 5; // 운동횟수; 처음 값은 0 지금은 squat 시연용이어서 5
int currentReps = 0; // 운동 횟수 카운트 변수

double correctX1 = 0, correctY1 = 0, correctZ1 = 0;  //올바른 운동 시작 자세
double correctX2 = 0, correctY2 = 0, correctZ2 = 0;  //올바른 중간 운동 자세
double correctX_v1 = 0, correctY_v1 = 0, correctZ_v1 = 0;  //올바른 운동 속도1
double correctX_v2 = 0, correctY_v2 = 0, correctZ_v2 = 0;  //올바른 운동 속도2
double* measuredX; 
double* measuredY; 
double* measuredZ;  //측정된 각도값들 저장
double measuredX_v = 0, measuredY_v = 0, measuredZ_v = 0;  //측정된 속도값 저장
//double measuredX_v2 = 0, measuredY_v2 = 0, measuredZ_v2 = 0;

// LED의 색 설정함수의 변수
int color = 0;
// 운동상태 LED의 각 핀을 9,10,11번으로 설정(빨강 = 11, 초록 = 10, 파랑 = 9)
int redPin1 = 11;
int greenPin1 = 10;
int bluePin1 = 9;
unsigned long previousMillis = 0; // LED의 상태가 업데이트된 시간을 기록할 변수
const long interval = 500;  // LED 상태 변경할 시간 지정 0.5초

void setup() {
  // 운동상태 LED setup
  pinMode(redPin1, OUTPUT);
  pinMode(greenPin1, OUTPUT);
  pinMode(bluePin1, OUTPUT);

  initSensor();
  Serial.begin(115200);
  caliSensor();   //  초기 센서 캘리브레이션 함수 호출
  past = millis(); // past에 현재 시간 저장  
}

void loop() {
  /********************************************
  앱으로 부터 어떤 운동시작할지 몇회 실시할지 블루투스로 전달받는 코드 필요
  ********************************************/
  
  //exercise값이 squat면 squat운동 시작
  if(exercise == squat) {
    
    // 실험을 통해 얻은 올바른 운동 자세, 속도 값들 
    correctY1 = -87.4552;  // 올바른 시작, 돌아왔을 때 자세
    correctY2 = 16.0;      // 올바른 내려갔을때 자세
    correctY_v1 = 9.19;    // 올바른 내려갈때의 속도
    correctY_v2 = -9.77;   // 올바른 올라올때의 속도
    
    //시작자세 취하기
    bool correctStart = 0;
    //int counter = 0;  
    unsigned long past2 = 0;  // 시간 저장용 변수들2
    Serial.println("시작자세를 취해주세요");  // 똑바로 선 자세, 센서는 허벅지 앞쪽 중앙, 무릎 위쪽에 X축이 하늘을 바라보게
    while(!correctStart){
      color = 2;
      setColor1(color);  // 운동상태 LED를 노란색으로 설정
      Serial.println("...");  
      getAngle();  //현재 신체 모션 감지
      correctStart = (angleFiY > (correctY1 - 10)) && (angleFiY < (correctY1 + 10));  //올바른 시작 자세에 있는지 판단
      if(correctStart) {  //올바른 시작 차세를 취하기 시작하면
        color = 0;
        setColor1(color);  // 운동상태 LED를 초록색으로 설정
        past2 = millis(); //시작했을 때의 시간 저장
        // 2초동안 계속 올바른 자세이면 기다린 뒤에 true의 correctStart를 넘기고 아니면 false를 넘김
        while(correctStart) {
          if( (millis() - past2) > 2000)
            break;  //correctStart가 true 상태로 while(correctStart) 탈출
          getAngle();
          correctStart = (angleFiY > (correctY1 - 10)) && (angleFiY < (correctY1 + 10));
          delay(20);
        }
        if(correctStart)
          break;  //앞에서 correctStart가 true 상태로 while문을 탈출 했다면 while(!correctStart) 탈출
        else
          correctStart = 0;
      }
    }
    
    while( currentReps < reps ) {
      
      //운동 시작
      Serial.println("운동을 시작합니다");
      redAlarm1();  //이전에 LED색이 빨간색인지 검사 아니면 초록색으로 설정
    
      // 운동 시작 안내가 나오고 내려가기 시작하는지 판단
      measuredY = new double[2];
      getAngle();
      measuredY[0] = angleFiY;
      measuredY[1] = angleFiY;
      // angleFiY값의 전후 차이가 3이상 나지 않으면 대기
      while( (measuredY[1] - measuredY[0]) < 2 ) {
        getAngle();
        measuredY[0] = measuredY[1];
        measuredY[1] = angleFiY;
        redAlarm1();  //이전에 LED색이 빨간색인지 검사 아니면 초록색으로 설정
        delay(20);
      }
      delete[] measuredY;
    
      // 중간지점까지 운동자세 판단
      unsigned long past3 = millis(); // 시간 저장용 변수3, 내려가기 시작할때의 시간 저장
      int squatPosture = -1; // 판단결과 저장 변수, 0 = 정확, 1 =  높음, 2 = 낮음
      int squatSpeed = -1; // 판단결과 저장 변수, 0 = 정확, 1 = 빠름, 2 = 느림
      bool correctCheckPoint = 1;
      while( angleFiY < 11) {  // -76이상 올라갈때까지 루프반복
        getAngle();
        redAlarm1();  //이전에 LED색이 빨간색인지 검사 아니면 초록색으로 설정
        if( angleFiY > -76)
          break;
        delay(20);
      }
      while( angleFiY < 11) {
        getAngle();
        redAlarm1();  //이전에 LED색이 빨간색인지 검사 아니면 초록색으로 설정
        if( angleFiY < -76) { // 허벅지가 덜 내려가고 다시 올라옴
          squatPosture = 1;
          Serial.println("너무 높습니다");
          color = 1;
          setColor1(color);
          previousMillis = millis();
          correctCheckPoint = 0;
          break;
        }
        delay(20);
      }
    
      // 중간지점에서 올라올때까지 운동자세 판단
      if(!correctCheckPoint) { // 덜 내려가고 다시 시작자세로 돌아온 경우
        //correctCheckPoint = 1;  // 다시 1로 reset하고 시작자세부터 다시 시작
      }
      else {
        // 내려간 속도 판단
        if( (millis() - past3) < 2000) {
          squatSpeed = 1;
          Serial.println("너무 빠릅니다.");
          color = 1;
          setColor1(color);
          previousMillis = millis();
        }
        else if( (millis() - past3) > 4000) {
          squatSpeed = 2;
          Serial.println("너무 느립니다.");
          color = 1;
          setColor1(color);
          previousMillis = millis();
        }
        else {
          squatSpeed = 0;
          Serial.println("정상 속도.");
          color = 0;
          setColor1(color);
        }
        
        // 다시 올라오는지 판단
        measuredY = new double[2];
        getAngle();
        measuredY[0] = angleFiY;
        measuredY[1] = angleFiY;
        // angleFiY값의 전후 차이가 -3이하 나지 않으면 아직 올라오는 중 아님
        while( (measuredY[1] - measuredY[0]) > -2) {
          getAngle();
          redAlarm1();  //이전에 LED색이 빨간색인지 검사 아니면 초록색으로 설정
          measuredY[0] = measuredY[1];
          measuredY[1] = angleFiY;
          if( angleFiY > 30 ) {
            squatPosture = 2;
            Serial.println("너무 낮습니다.");
            color = 1;
            setColor1(color);  // 너무 낮은 경우일때만 LED를 빨간색으로 설정할때 0.5초동안 유지하는게 아니라 자세가 낮은 동안만 설정
          }
          delay(20);
        }
        color = 0;
        setColor1(color);
        delete[] measuredY;
    
        //올라올때의 속도 판단
        unsigned long past4 = millis(); // 시간 저장용 변수4, 올라가기 시작할때의 시간 저장
        while( angleFiY >= -76 ) {
          getAngle();
          redAlarm1();  //이전에 LED색이 빨간색인지 검사 아니면 초록색으로 설정
          if( angleFiY < -76 ) {
            if( millis() - past4 < 2000) {
              squatSpeed = 1;
              Serial.println("너무 빠릅니다.");
              color = 1;
              setColor1(color);  
              previousMillis = millis();
            }
            else if( (millis() - past4) > 4000) {
              squatSpeed = 2;
              Serial.println("너무 느립니다.");
              color = 1;
              setColor1(color);
              previousMillis = millis();
            }
            else {
              squatSpeed = 0;
              Serial.println("정상 속도.");
              color = 0;
              setColor1(color);
            }
          }
          delay(20);
        }
        currentReps++;
      }
    }
  }
  
  exercise = 0;  //다시 0으로 초기화
  
}

void getAngle() {
  getData(); 
  getDT();
  
  double temp = sqrt(pow(AcX, 2) + pow(AcZ, 2));
  angleAcX = atan(AcY / temp);
  angleAcX *= RADIAN_TO_DEGREE;
  
  temp = sqrt(pow(AcY, 2) + pow(AcZ, 2));
  angleAcY = atan(-AcX / temp);
  angleAcY *= RADIAN_TO_DEGREE;

  //angleAcY = atan(-AcX / sqrt(pow(AcY, 2) + pow(AcZ, 2)));
  //angleAcY *= RADIAN_TO_DEGREE;
  // 가속도 센서로는 Z축 회전각 계산 불가함.
  
  // 가속도 현재 값에서 초기평균값을 빼서 센서값에 대한 보정
  angleGyX += ((GyX - averGyX) / DEG_PER_SEC) * dt;  //각속도로 변환
  angleGyY += ((GyY - averGyY) / DEG_PER_SEC) * dt;
  angleGyZ += ((GyZ - averGyZ) / DEG_PER_SEC) * dt;

  // 상보필터 처리를 위한 임시각도 저장
  double angleTmpX = angleFiX + angleGyX * dt;
  double angleTmpY = angleFiY + angleGyY * dt;
  double angleTmpZ = angleFiZ + angleGyZ * dt;

  // (상보필터 값 처리) 임시 각도에 0.96가속도 센서로 얻어진 각도 0.04의 비중을 두어 현재 각도를 구함.
  angleFiX = ALPHA * angleTmpX + (1.0 - ALPHA) * angleAcX;
  angleFiY = ALPHA * angleTmpY + (1.0 - ALPHA) * angleAcY;
  angleFiZ = angleGyZ;    // Z축은 자이로 센서만을 이용하열 구함.
  //Serial.print("AngleAcX:");
  //Serial.print(angleAcX);
  
  /***************************
  디버깅용 시리얼 모니터 출력
  테스트 다 끝나면 주석처리 필요
  ***************************/
  //if(count==10){
  //Serial.print("X: ");
  Serial.print(angleFiX);
  Serial.print(" ");
  //Serial.print("\t AngleAcY:");
  //Serial.print(angleAcY);
  //Serial.print(" Y: ");
  Serial.print(angleFiY);
  Serial.print(" ");
  //Serial.print("\t AngleGyZ:");
  //Serial.print(angleGyZ);
  //Serial.print(" Z: ");
  Serial.println(angleFiZ);
  //count =0;
  //}
  //count++;


//  Serial.print("Angle Gyro X:");
//  Serial.print(angleGyX);
//  Serial.print("\t\t Angle Gyro y:");
//  Serial.print(angleGyY);  
//  Serial.print("\t\t Angle Gyro Z:");
//  Serial.println(angleGyZ);
  delay(20);
}

double linearFit(double* measuredAngles, int counter) {
  int i, j, k, n;
  n = counter+1;
  double x[n], y[n], a;
  for(i = 0; i < n; i++){
    x[i] = i;
  }
  
  for(i = 0; i < n; i++){
    y[i] = measuredAngles[i];
  }
  
  double xsum = 0, x2sum = 0, ysum = 0, xysum = 0;
  for(i = 0; i < n; i++) {
      xsum += x[i]; // calculate sigma(xi)
      ysum += y[i]; // calculate sigma(yi)
      x2sum += pow(x[i], 2); // calculate sigma(xi^2)
      xysum += x[i]*y[i]; // calculate sigma(xi*yi)
  }
  a = (n*xysum - xsum*ysum)/(n*x2sum - xsum*xsum); // calculate slope
  return a;
}

void initSensor() {
  Wire.begin();
  Wire.beginTransmission(MPU_ADDR);   // I2C 통신용 어드레스(주소)
  Wire.write(0x6B);    // MPU6050과 통신을 시작하기 위해서는 0x6B번지에    
  Wire.write(0);
  Wire.endTransmission(true);
}

void getData() {
  Wire.beginTransmission(MPU_ADDR);
  Wire.write(0x3B);   // AcX 레지스터 위치(주소)를 지칭합니다
  Wire.endTransmission(false);
  Wire.requestFrom(MPU_ADDR, 14, true);  // AcX 주소 이후의 14byte의 데이터를 요청
  AcX = Wire.read() << 8 | Wire.read(); //두 개의 나뉘어진 바이트를 하나로 이어 붙여서 각 변수에 저장
  AcY = Wire.read() << 8 | Wire.read();
  AcZ = Wire.read() << 8 | Wire.read();
  Tmp = Wire.read() << 8 | Wire.read();
  GyX = Wire.read() << 8 | Wire.read();
  GyY = Wire.read() << 8 | Wire.read();
  GyZ = Wire.read() << 8 | Wire.read();
}

// loop 한 사이클동안 걸리는 시간을 알기위한 함수
void getDT() {
  now = millis();   
  dt = (now - past) / 1000.0;  
  past = now;
}

// 센서의 초기값을 20회 정도 평균값으로 구하여 저장하는 함수
void caliSensor() {
  double sumAcX = 0 , sumAcY = 0, sumAcZ = 0;
  double sumGyX = 0 , sumGyY = 0, sumGyZ = 0;
  getData();
  for (int i=0;i<20;i++) {
    getData();
    sumAcX+=AcX;  sumAcY+=AcY;  sumAcZ+=AcZ;
    sumGyX+=GyX;  sumGyY+=GyY;  sumGyZ+=GyZ;
    delay(20);
  }
  averAcX=sumAcX/20;  averAcY=sumAcY/20;  averAcZ=sumAcY/20;
  averGyX=sumGyX/20;  averGyY=sumGyY/20;  averGyZ=sumGyZ/20;
}

// 운동상태 LED 색 설정 함수, color가 0이면 초록색, 1이면 빨간색, 2이면 노란색으로 설정
void setColor1(int color) {
  if(color == 0) {
    analogWrite(redPin1, 0);
    analogWrite(greenPin1, 255);
    analogWrite(bluePin1, 0); 

  }
  else if(color == 1) {
    analogWrite(redPin1, 255);
    analogWrite(greenPin1, 0);
    analogWrite(bluePin1, 0);
  }
  else if(color == 2) {
    analogWrite(redPin1, 255);
    analogWrite(greenPin1, 255);
    analogWrite(bluePin1, 0);
  }
}

// 운동상태 LED의 빨간불이 0.5초간 켜졌는지 확인하는 함수
void redAlarm1() {
  if(color == 1) {
    if(millis() - previousMillis >= 500)
      color = 0;
      setColor1(color);  // 운동상태가 LED가 빨간색으로 일정시간 켜져있으면 초록색으로 변환
    }
    else{
      color = 0;
      setColor1(color);  // 운동상태 LED를 초록색으로 설정
    }
}

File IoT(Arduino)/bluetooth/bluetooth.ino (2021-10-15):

//블루투스 통신



#include <SoftwareSerial.h>
#include <MsTimer2.h>
SoftwareSerial blue(2,3);
String sth=" ";
int command=0;
boolean flag=false;

void checking() {
  //led 켬
  if(blue.available()){//들어온 명령이 있을 때
    while (blue.available()>1){//여러명령이 들어왔을경우 마지막 명령만 실행
      blue.read();
    }
    command=static_cast<int>(blue.read());
    switch(command){
      case 11://첫번째 종류의 운동(스쿼트) 시작
      flag=true;
      exercise=1;
      break;
      //case 12://두번째 종류의 운동 시작
      //flag=ture;
      //exercise=2;
      //break;
      case 2://멈추기
      flag=false;
      //측정중단함수
      break;
      default:
      blue.println(99);
    }
    
  }
  else if (!sth==' ') {//보낼것이 있을때
    blue.println(sth);
    sth=" ";
  }
  else if (flag==true){//명령도 없고 완료된 측정된 것도 없을때
    blue.println(5);//측정중
  }
  else{
    blue.println(6);//측정중이 아님
  }
  //led 끔
}

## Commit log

2021-10-03 bluetooth scan 기능 추가
2021-10-04 운동 시작전 페이지 작업중
2021-10-04 beforestart 페이지 UI 완성
2021-10-05 exercisepage 내용 추가, 디자인 기능 추가필요
2021-10-06 exercise 페이지 작업 디자인 편집중
2021-10-07 exercise page ui 완성(기능 추가 필요)
2021-10-08 afterSquats 페이지 작업중, 디자인 개선 필요
2021-10-08 PowerManual회로도
    [PowerManual.fzz]
2021-10-08 PowerManual 브레드보드
    [PowerManual.fzz]
2021-10-08 벤치프레스 exercisepage 작업
2021-10-09 회로구성 이미지 추가
2021-10-09 code 수정
2021-10-09 코드 수정
2021-10-09 회로도 이미지 추가
2021-10-09 디바이스 내부 추가
2021-10-09 height변경
2021-10-09 이미지 크기 변경
2021-10-09 이미지 크기 수정
2021-10-09 squats error page 작업중
2021-10-11 Add files via upload
    bluetooth 기본
2021-10-11 약간의 수정
2021-10-11 약간의 수정
    변수 초기화
    [bluetest.ino]
2021-10-12 overviwe 내용 추가
2021-10-13 powermanual 코드 업로드
    [PowerManualCorrectPosture.xlsx, PowerManualCorrectSpeed.xlsx]
2021-10-13 setup,loop 합침
    스쿼트 측정을 하나의 함수로 만들고 maintest에만 setup,loop를 남김
2021-10-14 폴더명 변경
    폴더명, 파일명에 따라 arduino ide에서 컴파일하는 순서가 달라져서 컴파일이 안되는것이였습니다
2021-10-15 전후 차이 3으로 수정
2021-10-15 PPT수정
2021-10-15 스쿼트자세 측정완료
2021-10-15 readme수정
2021-10-15 통신 코드 설명
2021-10-15 아두이노 모든 파일 하나로 합침
    이 파일로 작업해주세요
2021-10-16 리드미 수정
2021-10-16 디바이스 이미지 수정
2021-10-16 reaadme 이미지
2021-10-16 이미지 수정
2021-10-17 이미지 사이즈 수정
2021-10-17 size 수정
2021-10-17 회로도 업로드
    [PowerManual.fzz, PowerManualDevice.fzz]
2021-10-17 이미지 위치 수정
2021-10-17 이미지 추가
2021-10-18 Update measure.ino
    checkPosturewithLED.ino에서 스쿼트 측정을 함수로 만들고 loop를 간단히 만들고 블루투스 통신추가
2021-10-18 시연영상 업로드
2021-10-18 시연구성
2021-10-18 시연영상
2021-10-18 디렉토리정리
2021-10-19 IoT.ino 완성
2021-10-19 Create wokwitest.ino
    wokwi에서 돌아가게 하려고 했는데 serial에서 입력이 실제와 달라서 비교함수를 수정해야합니다.
    wokwi에서 돌리기 위해 bluetooth통신을 serial로 바꾸고 수정중입니다.
    [wokwitest.ino]
2021-10-20 app 구성 설명
2021-10-20 app 기술스택 정리
2021-10-20 Update wokwitest.ino
    Wokwi시연용 파일 업데이트
2021-10-20 Update README.md
    파일경로 수정
2021-10-20 착용사진
2021-10-20 착용샂니
2021-10-20 ppt업로드
2021-10-20 readme업로드
2021-10-20 ppt추가
2021-10-20 폴더명 변경
2021-10-20 기술 스택
2021-10-20 어플디자인 수정
    이미지 12장으로 수정
2021-10-20 readme삭제
2021-10-20 유튜브링크 재업로드
